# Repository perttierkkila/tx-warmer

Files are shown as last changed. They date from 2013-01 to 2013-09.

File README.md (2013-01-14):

This project aims to keep RC-flier's hands warm at winter. Nothing prevents
using this product with anything that needs constant heatpower.

### Author
Pertti Erkkilä (pertti.erkkila@gmail.com)

### License
GPLv3

### Story
In Finnish: http://www.kopterit.net/index.php/topic,17572.0.html

### Features
- constant heatpower stages (configurable) using PWM
- lipo-cell count auto-detection
- battery-monitor for cutoff

### Steps to get stuff working
- build hardware
- get Arduino 1.0.1 (1.0.2 won't work)
- get arduino-tiny -libraries (core + PinChangeInterrupt): http://code.google.com/p/arduino-tiny/
- suitable programmer (Arduino as ISP works well)
- for a new chip, burn bootloader
- burn firmware

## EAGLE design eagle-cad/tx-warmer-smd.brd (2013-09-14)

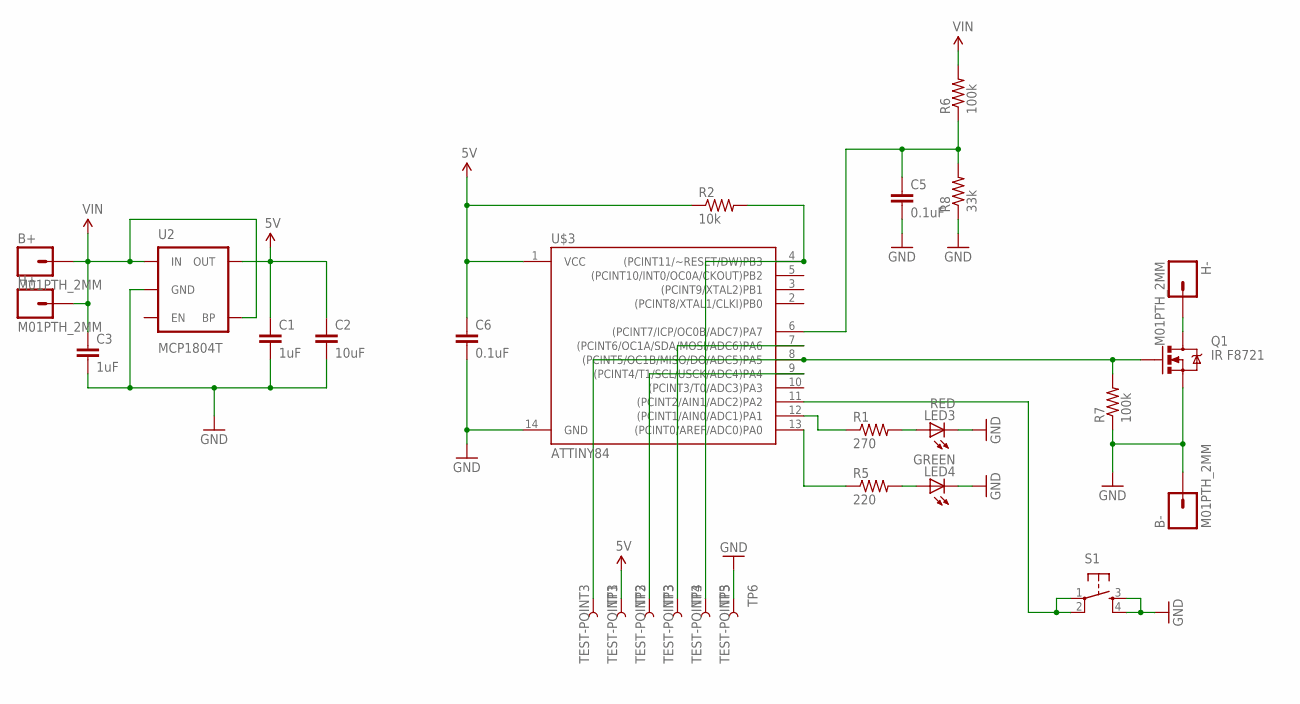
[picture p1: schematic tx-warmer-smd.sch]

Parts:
B+: M01PTH_2MM; 1X01_2MM
B-: M01PTH_2MM; 1X01_2MM
C1, C3: 1uF; 0805
C2: 10uF; 0805
C5, C6: 0.1uF; 0805
H+: M01PTH_2MM; 1X01_2MM
H-: M01PTH_2MM; 1X01_2MM
LED3: RED; LED-1206
LED4: GREEN; LED-1206
Q1: IR F8721; SO08
R1: 270; 0805
R2: 10k; 0805
R5: 220; 0805
R6, R7: 100k; 0805
R8: 33k; 0805
S1: TAC_SWITCHSMD; TACTILE_SWITCH_SMD
TP1, TP2, TP3, TP4, TP5, TP6: TEST-POINT3; PAD.03X.03
U2: MCP1804T; SOT23-5
U$3: ATTINY84; SO14

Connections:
5V: C1.1, C2.1, C6.1, R2.1, TP2.P$1, U2.5 (OUT), U$3.1 (VCC)
GND: B-.1, C1.2, C2.2, C3.2, C5.2, C6.2, LED3.C, LED4.C, Q1.1 (S), Q1.2 (S), Q1.3 (S), R7.1, R8.1, S1.3, S1.4, TP6.P$1, U2.2 (GND), U$3.14 (GND)
unnamed: S1.1, S1.2, U$3.11 ((PCINT2/AIN1/ADC2)PA2)
unnamed: C5.1, R6.1, R8.2, U$3.6 ((PCINT7/ICP/OC0B/ADC7)PA7)
unnamed: TP4.P$1, U$3.7 ((PCINT6/OC1A/SDA/MOSI/ADC6)PA6)
unnamed: TP3.P$1, U$3.9 ((PCINT4/T1/SCL/USCK/ADC4)PA4)
unnamed: Q1.4 (G), R7.2, TP1.P$1, U$3.8 ((PCINT5/OC1B/MISO/DO/ADC5)PA5)
unnamed: R1.1, U$3.12 ((PCINT1/AIN0/ADC1)PA1)
unnamed: H-.1, Q1.5 (D), Q1.6 (D), Q1.7 (D), Q1.8 (D)
unnamed: R5.1, U$3.13 ((PCINT0/AREF/ADC0)PA0)
unnamed: R2.2, TP5.P$1, U$3.4 ((PCINT11/~RESET/DW)PB3)
unnamed: LED3.A, R1.2
unnamed: LED4.A, R5.2
VIN: B+.1, C3.1, H+.1, R6.2, U2.1 (IN), U2.4 (BP)

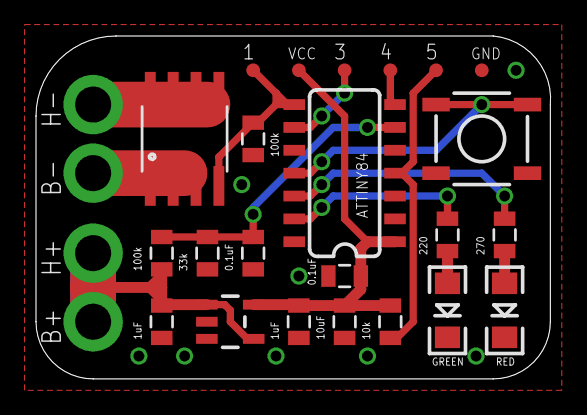
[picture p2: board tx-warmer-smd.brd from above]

Board: 2 copper layers, 28.6 x 19.0 mm, 27 parts (0 on the bottom side), 14 nets.

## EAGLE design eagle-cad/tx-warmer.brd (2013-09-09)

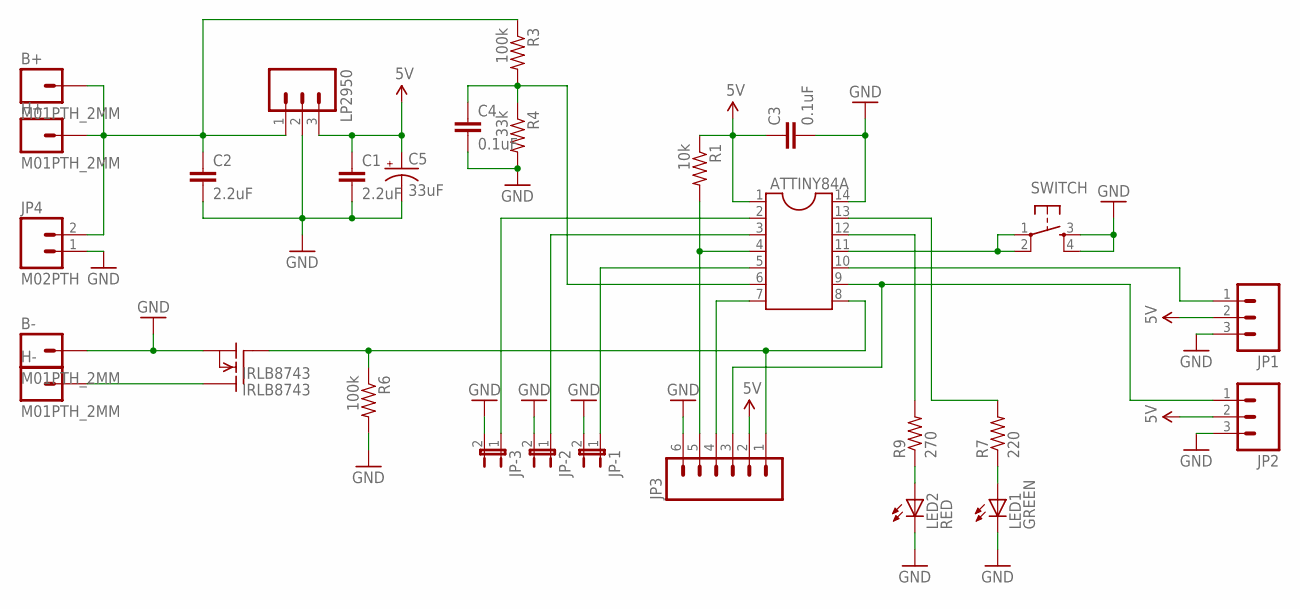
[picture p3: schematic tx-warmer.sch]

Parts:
ATTINY84A: DIL14S; SOCKET-14
B+: M01PTH_2MM; 1X01_2MM
B-: M01PTH_2MM; 1X01_2MM
C1, C2: 2.2uF; CAP-PTH-5MM
C3, C4: 0.1uF; CAP-PTH-SMALLEZ
C5: 33uF; CPOL-RADIAL-10UF-25V
H+: M01PTH_2MM; 1X01_2MM
H-: M01PTH_2MM; 1X01_2MM
IRLB8743: IRLB8743; TO220
JP1, JP2: M03PTH; 1X03
JP3: M06SIP; 1X06
JP4: M02PTH; 1X02
JP-1, JP-2, JP-3: JUMPER-2SMD-NO; SJ_2S-NO
LED1: GREEN; LED5MM-KIT
LED2: RED; LED5MM-KIT
LP2950: M031X03_NO_SILK; 1X03_NO_SILK
R1: 10k; AXIAL-0.3EZ
R3, R6: 100k; AXIAL-0.3EZ
R4: 33k; AXIAL-0.3EZ
R7: 220; AXIAL-0.3EZ
R9: 270; AXIAL-0.3EZ
SWITCH: TAC_SWITCHPTH; TACTILE-PTH

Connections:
5V: ATTINY84A.1, C1.1, C3.1, C5.1 (+), JP1.2, JP2.2, JP3.2, LP2950.3, R1.P$1 (1)
GND: ATTINY84A.14, B-.1, C1.2, C2.2, C3.2, C4.2, C5.2 (-), IRLB8743.3 (S), JP1.3, JP2.3, JP3.6, JP4.1, JP-1.2, JP-2.2, JP-3.2, LED1.K (C), LED2.K (C), LP2950.2, R4.P$2 (2), R6.P$2 (2), SWITCH.3, SWITCH.4
unnamed: ATTINY84A.9, JP2.1, JP3.3
unnamed: ATTINY84A.7, JP3.4
unnamed: ATTINY84A.10, JP1.1
unnamed: B+.1, C2.1, H+.1, JP4.2, LP2950.1, R3.P$1 (1)
unnamed: ATTINY84A.5, JP-1.1
unnamed: ATTINY84A.8, IRLB8743.1 (G), JP3.1, R6.P$1 (1)
unnamed: ATTINY84A.6, C4.1, R3.P$2 (2), R4.P$1 (1)
unnamed: LED2.A, R9.P$1 (1)
unnamed: LED1.A, R7.P$1 (1)
unnamed: ATTINY84A.4, JP3.5, R1.P$2 (2)
unnamed: ATTINY84A.12, R9.P$2 (2)
unnamed: ATTINY84A.11, SWITCH.1, SWITCH.2
unnamed: ATTINY84A.13, R7.P$2 (2)
unnamed: H-.1, IRLB8743.2 (D)
unnamed: ATTINY84A.3, JP-2.1
unnamed: ATTINY84A.2, JP-3.1

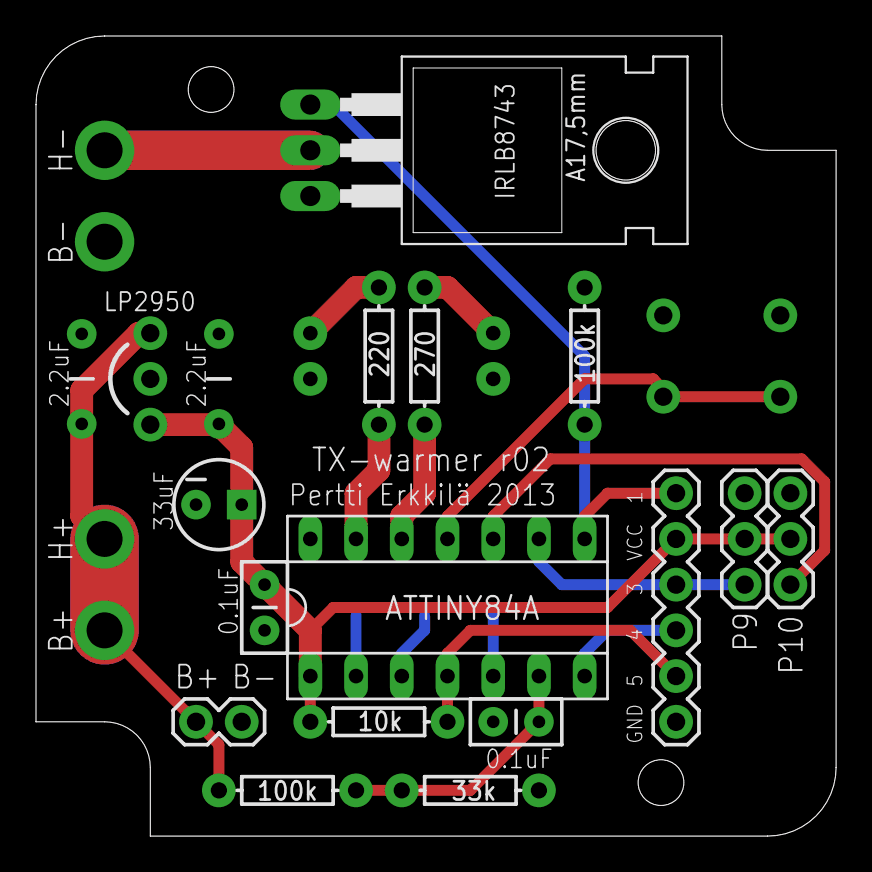
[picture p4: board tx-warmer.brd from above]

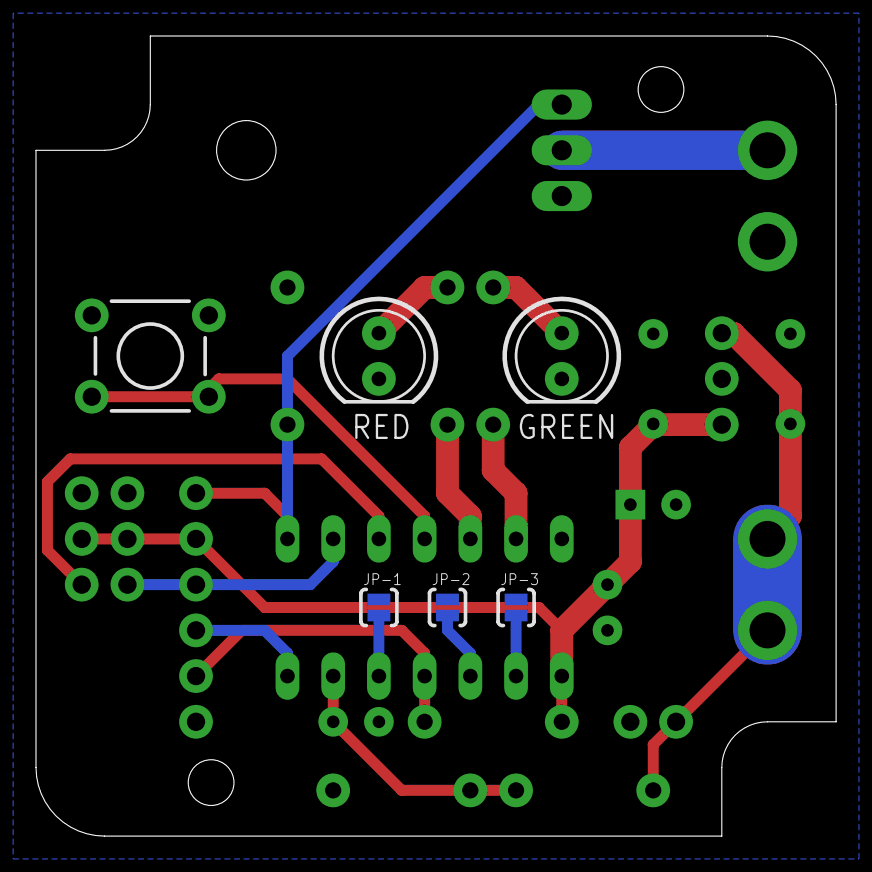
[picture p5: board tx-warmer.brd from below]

Board: 2 copper layers, 44.5 x 44.5 mm, 28 parts (6 on the bottom side), 18 nets.

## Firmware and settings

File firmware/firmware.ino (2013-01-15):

/****************************************************************
 * TX-warmer firmware v1.0, GPLv3-licence
 * Author    Pertti Erkkilä (pertti.erkkila@gmail.com)
 * Hardware  http://www.kopterit.net/index.php/topic,17572.0.html
 ****************************************************************/

#include <PinChangeInterrupt.h>

// TODO
// pwm prescaler
// sleep-mode
// sizeof-array

// heater element resistance, mOhm
const long HEATER_RESISTANCE = 1900; 

// heater element power settings, watts
const int HEATER_POWER[] = {
  10, 20, 30, 40, 50};
// count of HEATER_POWER-elements
const int HEATER_POWER_SIZE = 5;

// battery resistor divider, kOhm
const int ADC_RESISTOR_HIGH = 100;
const int ADC_RESISTOR_LOW = 33;

// Lipo-specific settings per cell, mV
const int LIPO_CUTOFF_VOLTAGE = 3650;
const int LIPO_CRITICAL_VOLTAGE = 3500;

// ATtiny pin mappings
// for ADC, use ADC-channel number
// other pins, running order skipping VCC, RESET and GND (eg pin2 = 1)
const int PIN_BATTERY = PA7;
const int PIN_GREEN = 10;
const int PIN_RED = 9;
const int PIN_PWM = 5;
const int PIN_BUTTON = 8;
const int PIN_DIP1 = 4;
const int PIN_DIP2 = 2;
const int PIN_DIP3 = 7;
const int PIN_DIP4 = 6;

// selected power-stage
// > 0: selected power stage from array
//  0: PWM off, battery OK
// -1: cutoff voltage triggered
// -2: critical voltage triggered
const int STAGE_OK = 0;
const int STAGE_CUTOFF = -1;
const int STAGE_CRITICAL = -2;
volatile int stage = STAGE_OK;

// current dutyCycle, valid range 0-255
volatile int dutyCycle = 0;

// Battery saving voltages, mV
// below cutoff = stop PWM, blink led
volatile long cutoffVoltage = 0;
// below critical = shutdown everything, sleep-mode
volatile long criticalVoltage = 0;

// for button debounce, ms
const int BUTTON_DEBOUNCE_DURATION = 50;
volatile unsigned long buttonLastPressed = 0;
volatile boolean stageChanged = false;

void setup() {
  // wait for user after plugging battery
  delay(1000);

  // pin setup
  pinMode(PIN_GREEN, OUTPUT);
  pinMode(PIN_RED, OUTPUT);
  pinMode(PIN_PWM, OUTPUT);
  pinMode(PIN_BATTERY, INPUT);

  pinMode(PIN_BUTTON, INPUT);
  digitalWrite(PIN_BUTTON, HIGH); // enable INPUT_PULLUP, not supported with attiny

  pinMode(PIN_DIP1, INPUT);
  digitalWrite(PIN_DIP1, HIGH); // enable INPUT_PULLUP, not supported with attiny

  pinMode(PIN_DIP2, INPUT);
  digitalWrite(PIN_DIP2, HIGH); // enable INPUT_PULLUP, not supported with attiny

  pinMode(PIN_DIP3, INPUT);
  digitalWrite(PIN_DIP3, HIGH); // enable INPUT_PULLUP, not supported with attiny

  pinMode(PIN_DIP4, INPUT);
  digitalWrite(PIN_DIP4, HIGH); // enable INPUT_PULLUP, not supported with attiny

  // calculate cutoff and critical voltages
  long batteryVoltage = readVoltage();
  int cellCount = calculateCellCount(batteryVoltage);

  // request at least 2 cells (LDO shouldn't even work = error)
  if (cellCount < 1)
    stage = STAGE_CUTOFF;

  cutoffVoltage = cellCount * LIPO_CUTOFF_VOLTAGE;
  criticalVoltage = cellCount * LIPO_CRITICAL_VOLTAGE;

  // indicate cell count by blinking both leds
  for (int i = 0; i < cellCount; i++) {
    digitalWrite(PIN_GREEN, HIGH);
    digitalWrite(PIN_RED, HIGH);
    delay(100);
    digitalWrite(PIN_GREEN, LOW);
    digitalWrite(PIN_RED, LOW);
    delay(750);
  }

  attachPcInterrupt(PIN_BUTTON, buttonPressed, FALLING);
  delay(500);
}

void loop() {
  if (stage == STAGE_CRITICAL) {
    // critical-stage, sleep
    delay(1000);
    return;
  }

  // check battery and adjust stage if needed
  long batteryVoltage = readVoltage();
  if (batteryVoltage < criticalVoltage) {
    // critical-stage reached, pwm and leds off
    stage = STAGE_CRITICAL;
    analogWrite(PIN_PWM, 0);
    digitalWrite(PIN_GREEN, LOW);
    digitalWrite(PIN_RED, LOW);
    return;
  }
  if (batteryVoltage < cutoffVoltage && stage > STAGE_CUTOFF) {
    // cutoff-stage reached, pwm off
    stage = STAGE_CUTOFF;
    analogWrite(PIN_PWM, 0);
  }

  if (stage == STAGE_CUTOFF) {
    // cutoff-stage, blink green led, red off
    digitalWrite(PIN_RED, LOW);
    digitalWrite(PIN_GREEN, HIGH);
    delay(10);
    digitalWrite(PIN_GREEN, LOW);
    delay(1500);
    return;
  }

  // running fine, keep green on
  digitalWrite(PIN_GREEN, HIGH);

  // calculate dutycycle and change if needed
  int newDutyCycle = calculateDutyCycle(batteryVoltage);
  if (dutyCycle != newDutyCycle) {
    dutyCycle = newDutyCycle;
    // prescaler TCCR1B = _BV(CS0x) | _BV(CS0x); 
    analogWrite(PIN_PWM, newDutyCycle);
  }

  // blink red according dutycycle, total led cycle duration 1.6secs
  if (dutyCycle > 0) {
    digitalWrite(PIN_RED, HIGH);
    stageChangeAwareDelay(dutyCycle * 6);
  }
  digitalWrite(PIN_RED, LOW);
  stageChangeAwareDelay((255 - dutyCycle) * 6);

  // reset variable
  stageChanged = false;
}

void stageChangeAwareDelay(int duration) {
  for (int i = 0; i < (duration / 10); i++) {
    if (stageChanged == true) return;
    delay(10);
  }
}

void buttonPressed() {
  // stage check, not applicable when cutoff reached
  if (stage < 0) return;

  // check debounce
  unsigned long time = millis();
  if ((time - BUTTON_DEBOUNCE_DURATION) < buttonLastPressed) return;
  buttonLastPressed = time;

  // next stage and check overflow
  stage++;
  if (stage > HEATER_POWER_SIZE)
    stage = 0;

  // break blinding delay
  stageChanged = true;
}

long readVoltage() {
  return readADC(PIN_BATTERY, ADC_RESISTOR_HIGH, ADC_RESISTOR_LOW);
}

// calculate dutycycle according stage (1-based index)
int calculateDutyCycle(long voltage) {
  if (stage <= STAGE_OK || stage > HEATER_POWER_SIZE)
    return 0;
  return calculateDutyCycle(voltage, HEATER_RESISTANCE, HEATER_POWER[stage-1]);
}

//-------------------------------------------------
// Library stuff

// calculate lipo-cell count
// voltage=mV
int calculateCellCount(long voltage) {
  if (voltage <= 0)
    return 0;
  return (voltage - 100) / 4200 + 1;
}

// calculate PWM dutyCycle, output 0-255
// voltage=mV, resistance=mOhm, power=W
int calculateDutyCycle(long voltage, long resistance, long power) {
  if (voltage < 1 || resistance < 1 || power < 1)
    return 0;
  long wantedCurrent  = 1000000 * power / voltage;
  long maxCurrent = 1000 * voltage / resistance;

  if (wantedCurrent >= maxCurrent)
    return 255;
  return 255 * wantedCurrent / maxCurrent;
}

// Read ADC five times and calculate resistor divider
long readADC(int pin, int resistorHigh, int resistorLow) {
  // read 5 samples
  long result = 0;
  for (int i = 0; i < 5; i++) {
    delay(10);
    result += analogRead(pin);
  }
  // to mV (assumed 5V reference)
  result = (1000 * result) / 1023;

  // solve divider
  result = (result * (resistorHigh + resistorLow)) / resistorLow;
  return result;
}

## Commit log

2013-01-06 Eagle CAD schema and board v1.4
    [tx-warmer.brd, tx-warmer.sch]
2013-01-06 Arduino attiny-firmware
2013-01-14 Tweaked firmware. Lower cell cut-offs and tested prescaler.
2013-01-15 Changed voltage regulator MCP1702 to LP2950 (formed leads)
    [tx-warmer.brd, tx-warmer.sch]
2013-01-15 Modified voltage divider to support higher voltages (max now 20.1V)
    [tx-warmer.brd, tx-warmer.sch]
2013-01-15 Removed ISP-header. Mainly useless and made room for future changes
    [tx-warmer.brd, tx-warmer.sch]
2013-01-15 Moved PWM from pin5 to pin8
    Reason for this to utilizer timer1 and allows using prescaler without
    interference to delay-methods.
    [tx-warmer.brd, tx-warmer.sch]
2013-01-15 Added DIP switches and refactored layout
    Switches allow to configure software and reduces firmware variations.
    [tx-warmer.brd, tx-warmer.sch]
2013-01-16 Minor tweaks to board
    [tx-warmer.brd]
2013-01-17 Flipped DIP-switches
    [tx-warmer.brd, tx-warmer.sch]
2013-01-17 Changed capacitors near regulator from 0.1" to 0.2" spacing
    To avoid confusion with 0.1uF caps and straight legs sit better at board.
    [tx-warmer.brd, tx-warmer.sch]
2013-01-17 Moved CPU a bit to make room for big cap
    Fixed visibility of new caps.
    [tx-warmer.brd]
2013-01-17 Added numbering for DIP switches
    Allows to use jumper wires or 0Ohm resistor instead dip-switches if
    setup is pretty permanent.
    [tx-warmer.brd]
2013-01-21 Changed 4P-switch to 6P-switch to utilize all inputs
    [tx-warmer.brd, tx-warmer.sch]
2013-09-03 SMD-version, r1
    [tx-warmer-smd.brd, tx-warmer-smd.sch]
2013-09-06 Minor updates to SMD-version
    [tx-warmer-smd.brd, tx-warmer-smd.sch]
2013-09-06 Added GND-plane to top
    [tx-warmer.brd]
2013-09-06 Removed DIP:s, added two sensor ports, bat-pins and prog-interface
    [tx-warmer.brd, tx-warmer.sch]
2013-09-06 Added SMD-jumpers to empty MC-pins
    [tx-warmer.brd, tx-warmer.sch]
2013-09-09 Minor fixed to schema/board
    [tx-warmer.brd, tx-warmer.sch]
2013-09-10 Fixed ldo shutdown-pin and checked values for res/caps
    [tx-warmer-smd.brd, tx-warmer-smd.sch]
2013-09-14 Added top gnd-plane
    [tx-warmer-smd.brd, tx-warmer-smd.sch]

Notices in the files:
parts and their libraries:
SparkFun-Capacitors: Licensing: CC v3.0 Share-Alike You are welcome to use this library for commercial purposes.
